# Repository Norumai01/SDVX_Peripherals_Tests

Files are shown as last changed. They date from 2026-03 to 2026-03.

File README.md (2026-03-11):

# controller_subtests

Breadboard prototyping tests for a custom Sound Voltex (SDVX) controller built on the Raspberry Pi Pico 2 H (RP2350).

Each subfolder is a self-contained test with its own `CMakeLists.txt` and `main.c`.

---

## Project Structure

```
controller_subtests/
├── CMakeLists.txt          ← top-level, registers all subtests
├── pico_sdk_import.cmake
├── serial_monitor.py       ← Python serial monitor for debugging
├── mx_switch_test/
│   ├── CMakeLists.txt
│   └── main.c              ← Cherry MX Brown button + onboard LED test
└── encoder_test/
    ├── CMakeLists.txt
    └── main.c              ← Bourns PEC11R rotary encoder test
```

---

## Hardware

| Component | Part |
|---|---|
| Microcontroller | Raspberry Pi Pico 2 H (RP2350, pre-soldered headers) |
| Buttons | Cherry MX Brown switches (jumper wires soldered directly to pins) |
| Encoders | Bourns PEC11R-xxxxK (no detents, with push switch) |

---

## Subtest: mx_switch_test

Tests a single Cherry MX Brown switch on GPIO 0. Jumper wires are soldered directly to the two switch pins. Toggles the onboard LED on press/release and prints state over USB serial.

**Wiring:**
```
Switch Pin 1  → GPIO 0  (pin 1)
Switch Pin 2  → GND
```

> **Note:** Uses the Pico's internal pull-up — no external resistor needed. Pin reads HIGH at rest and LOW when pressed.

---

## Subtest: encoder_test

Tests a Bourns PEC11R rotary encoder — quadrature rotation via interrupt and push switch via polling.

**Wiring:**
```
ENC A    → GPIO 10  (pin 14)
ENC C    → GND
ENC B    → GPIO 11  (pin 15)
SW pin 1 → GPIO 12  (pin 16)
SW pin 2 → GND
```

**How it works:**
- An interrupt fires on every rising/falling edge of channel A
- Inside the ISR, A and B are compared — if they differ, direction is CW (+1), if same, direction is CCW (-1)
- The push switch is polled in the main loop with debounce

---

## Building

Requires the [Raspberry Pi Pico SDK](https://github.com/raspberrypi/pico-sdk). Set `PICO_SDK_PATH` in your environment or let CLion handle it via the CMake Environment field.

```bash
mkdir cmake-build-debug && cd cmake-build-debug
cmake ..
make
```

Each subtest outputs its own `.uf2` into its own subfolder:
```
cmake-build-debug/
├── mx_switch_test/
│   └── mx_switch_test.uf2
└── encoder_test/
    └── encoder_test.uf2
```

**To flash:**
1. Hold BOOTSEL on the Pico while plugging in USB
2. It mounts as a drive called `RP2350`
3. Drag and drop the `.uf2` onto the `RP2350` drive

---

## Serial Monitor

Use the included `serial_monitor.py` to watch output over USB serial.

**Requirements:**
```bash
pip install pyserial
```

**Run:**
```bash
python serial_monitor.py
```

Defaults to `COM3` at `115200` baud. Edit `PORT` at the top of the script if your Pico is on a different port (check Device Manager → Ports (COM & LPT)).

## CLion Serial Monitor (alternative)

CLion has a built-in serial monitor under **Tools → Serial Monitor**.

Settings that must be enabled for it to work with the Pico:
- **Enable HW Flow Control** — on
- **Local Echo** — on
- **DTR** — enabled (this is what actually triggers the Pico to send output)

Without DTR enabled, the monitor connects but receives nothing.

---

## Notes

- Both encoder A and B pins use the Pico's internal pull-ups — no external resistors needed for basic testing
- For final PCB design, add a hardware filter (10KΩ + 0.01µF on each channel) per the PEC11R datasheet recommendation to reduce contact bounce at higher RPM
- The encoder's position counter is unbounded (`volatile int`) — for HID use, report the delta each frame rather than an absolute value

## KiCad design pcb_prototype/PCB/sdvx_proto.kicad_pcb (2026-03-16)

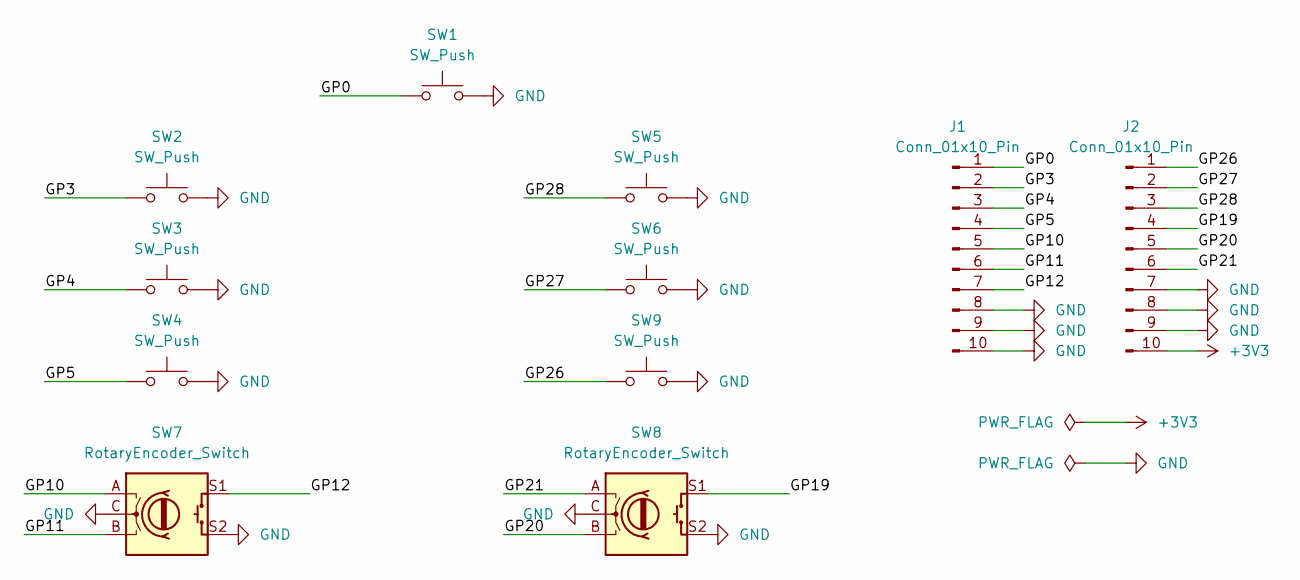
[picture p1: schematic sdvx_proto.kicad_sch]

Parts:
J1, J2: Conn_01x10_Pin; PinHeader_1x10_P2.54mm_Vertical
SW1, SW2, SW3, SW4, SW5, SW6, SW9: SW_Push; MX-Solderable-1U
SW7, SW8: RotaryEncoder_Switch; RotaryEncoder_Alps_EC11E-Switch_Vertical_H20mm

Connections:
+3V3: J2.10
/GP0: J1.1, SW1.1
/GP3: J1.2, SW2.1
/GP4: J1.3, SW3.1
/GP5: J1.4, SW4.1
/GP10: J1.5, SW7.A
/GP11: J1.6, SW7.B
/GP12: J1.7, SW7.S1
/GP19: J2.4, SW8.S1
/GP20: J2.5, SW8.B
/GP21: J2.6, SW8.A
/GP26: J2.1, SW9.1
/GP27: J2.2, SW6.1
/GP28: J2.3, SW5.1
GND: J1.8, J1.9, J1.10, J2.7, J2.8, J2.9, SW1.2, SW2.2, SW3.2, SW4.2, SW5.2, SW6.2, SW7.C, SW7.S2, SW8.C, SW8.S2, SW9.2

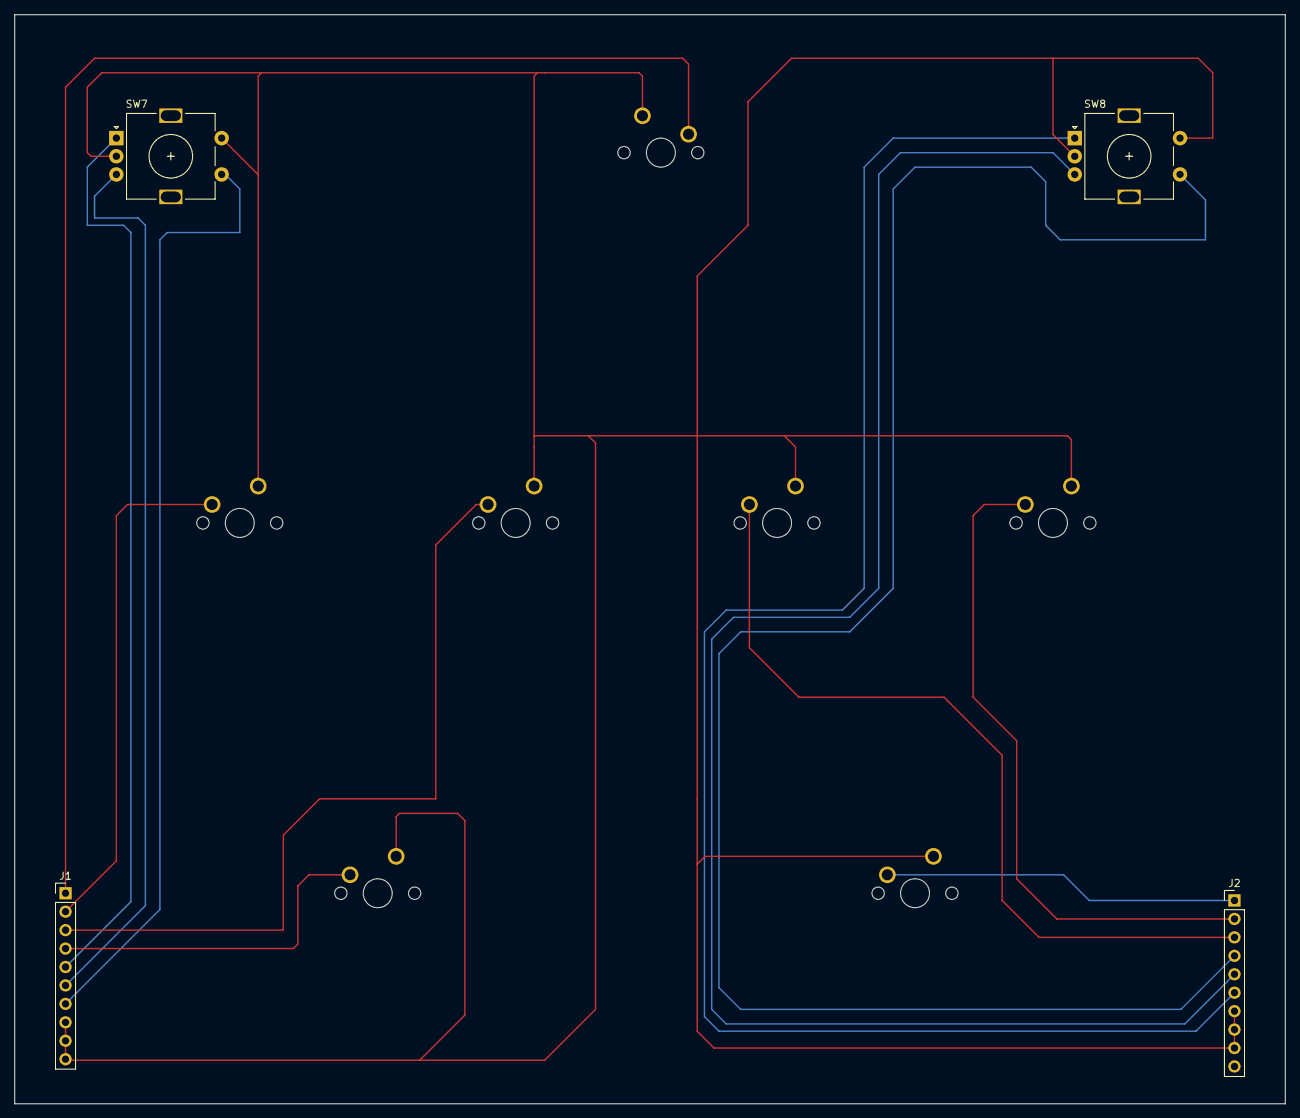
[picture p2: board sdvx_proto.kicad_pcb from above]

Board: 2 copper layers, 175.0 x 150.0 mm, 11 parts (1 on the bottom side), 14 nets.

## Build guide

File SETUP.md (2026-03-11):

# CLion + Pico 2 Setup Guide (Windows)

---

## First-Time Setup

Only needs to be done once per machine.

### 1. Install Python

Download and run the standalone installer from [python.org](https://python.org). During install, check **"Add Python to PATH"**.

Verify in a new PowerShell window:
```powershell
python --version
```

### 2. Install Git

Download from [git-scm.com](https://git-scm.com). Verify in a new PowerShell window:
```powershell
git --version
```

### 3. Clone the Pico SDK and Examples

Create a folder for your Pico work (example used here: `C:\pico`), then clone everything into it:
```powershell
cd C:\pico

git clone https://github.com/raspberrypi/pico-sdk.git --branch master
cd pico-sdk
git submodule update --init
cd ..

git clone https://github.com/raspberrypi/pico-examples.git --branch master
git clone https://github.com/raspberrypi/pico-extras.git
```

> You can use any folder you like. Just keep track of it — you'll need the path in later steps.

### 4. Install the ARM GNU Toolchain

Download the Windows toolchain from the [ARM Developer site](https://developer.arm.com/downloads/-/arm-gnu-toolchain-downloads). Extract it into your pico folder, e.g.:
```
C:\pico\arm_gnu_toolchain\
```

You should see folders called `bin`, `lib`, `arm-none-eabi`, etc. inside it.

### 5. Set Environment Variables

1. Press `Win` → search **"Environment Variables"** → click **"Edit the system environment variables"**
2. Click **Environment Variables...**
3. Under **User variables**, click **New** for each of the following:

| Variable Name | Value (adjust to your actual folder) |
|---|---|
| `PICO_SDK_PATH` | `C:\pico\pico-sdk` |
| `PICO_TOOLCHAIN_PATH` | `C:\pico\arm_gnu_toolchain` |
| `PICO_EXTRAS_PATH` | `C:\pico\pico-extras` |

4. Click OK on all dialogs, then **restart any open terminals or CLion** for changes to take effect.

### 6. Install CLion

Download and install CLion from [jetbrains.com/clion](https://www.jetbrains.com/clion/).

### 7. Configure the CLion Toolchain

Go to **File → Settings → Build, Execution, Deployment → Toolchains**

- Click **+** and select **MinGW**
- Set the C Compiler to your toolchain's gcc, e.g.:
  ```
  C:\pico\arm_gnu_toolchain\bin\arm-none-eabi-gcc.exe
  ```
- Set the C++ Compiler to:
  ```
  C:\pico\arm_gnu_toolchain\bin\arm-none-eabi-g++.exe
  ```

> **Why MinGW?** Picotool is a Windows binary that gets built during compilation using CLion's bundled MinGW GCC. Your actual Pico firmware uses the ARM compiler. Both are needed.

### 8. Install pyserial (for serial monitor)

```powershell
pip install pyserial
```

---

## Per-Project Setup

Do this every time you create a new project.

### 1. Create the Project Folder Structure

```
your_project/
├── CMakeLists.txt
├── pico_sdk_import.cmake    ← copy this from the SDK
└── src/
    └── main.c
```

Copy `pico_sdk_import.cmake` from your SDK folder:
```
<your PICO_SDK_PATH>\external\pico_sdk_import.cmake
```

### 2. CMakeLists.txt Template

Replace `YOUR_PROJECT_NAME` with your actual project name:

```cmake
cmake_minimum_required(VERSION 3.13)

include(pico_sdk_import.cmake)

project(YOUR_PROJECT_NAME C CXX ASM)
set(CMAKE_C_STANDARD 11)
set(CMAKE_CXX_STANDARD 17)

pico_sdk_init()

add_executable(YOUR_PROJECT_NAME
    src/main.c
)

target_link_libraries(YOUR_PROJECT_NAME
    pico_stdlib
    hardware_gpio
)

pico_enable_stdio_usb(YOUR_PROJECT_NAME 1)
pico_enable_stdio_uart(YOUR_PROJECT_NAME 0)

pico_add_extra_outputs(YOUR_PROJECT_NAME)
```

### 3. Open the Project in CLion

**File → Open** → select your project folder → OK

### 4. Configure CMake Settings

Go to **File → Settings → Build, Execution, Deployment → CMake**

**Toolchain:** MinGW

**CMake options** (replace `<TOOLCHAIN_PATH>` with your actual `PICO_TOOLCHAIN_PATH`):
```
-G Ninja -DPICO_BOARD=pico2 -DCMAKE_C_COMPILER="<TOOLCHAIN_PATH>\bin\arm-none-eabi-gcc.exe" -DCMAKE_CXX_COMPILER="<TOOLCHAIN_PATH>\bin\arm-none-eabi-g++.exe"
```

**Environment** (replace each `<...>` with your actual paths):
```
PICO_SDK_PATH=<your pico-sdk folder>;PICO_TOOLCHAIN_PATH=<your arm_gnu_toolchain folder>;PICO_EXTRAS_PATH=<your pico-extras folder>
```

Click **Apply → OK**.

### 5. Reset CMake and Build

**Tools → CMake → Reset Cache and Reload Project**

Then select your target from the dropdown at the top right and hit the **hammer icon** to build.

### 6. Flash to Pico

1. Hold **BOOTSEL** and plug in the Pico via USB
2. It mounts as a drive called `RP2350`
3. Find your `.uf2` in:
   ```
   your_project\cmake-build-debug-mingw\your_project.uf2
   ```
4. Drag and drop it onto the `RP2350` drive
5. The Pico reboots and runs your firmware

### 7. View Serial Output

Run in Python (with Pico already plugged in and running):

**Requirements:**
```bash
pip install pyserial
```

**Run:**
```bash
python serial_monitor.py
```

Defaults to `COM3` at `115200` baud. Edit `PORT` at the top of the script if your Pico is on a different port (check Device Manager → Ports (COM & LPT)).

> Check **Device Manager → Ports (COM & LPT)** if your Pico is not on COM3.

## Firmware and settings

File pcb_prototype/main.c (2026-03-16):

//
// main.c
// SDVX HID test — 1 button + 1 rotary encoder as a USB gamepad
//

#include <stdlib.h>
#include <stdio.h>
#include <string.h>

#include "bsp/board_api.h"
#include "tusb.h"
#include "usb_descriptors.h"
#include "hardware/gpio.h"

//--------------------------------------------------------------------+
// Pin Definitions
//--------------------------------------------------------------------+

#define BUTTON_START  0
#define BUTTON_BT_A   3
#define BUTTON_BT_B   4
#define BUTTON_BT_C   28
#define BUTTON_BT_D   27
#define BUTTON_FX_L   5
#define BUTTON_FX_R   26

#define ENC_L_A       10 // VOL-L button
#define ENC_L_B       11
#define ENC_L_SW      12  // encoder push button
#define ENC_R_A       21  // VOL-R button
#define ENC_R_B       20
#define ENC_R_SW      19  // encoder push button


//--------------------------------------------------------------------+
// Encoder State
//--------------------------------------------------------------------+

volatile int enc_l_position = 0;
volatile int enc_r_position = 0;

void encoder_isr(uint gpio, uint32_t events)
{
  switch (gpio) {
    case ENC_L_A: {
      bool a = gpio_get(ENC_L_A);
      bool b = gpio_get(ENC_L_B);
      enc_l_position += (a != b) ? 1 : -1;
      break;
    }
    case ENC_R_A: {
      bool a = gpio_get(ENC_R_A);
      bool b = gpio_get(ENC_R_B);
      enc_r_position += (a != b) ? 1 : -1;
      break;
    }
    default:
      return;
  }
}

//--------------------------------------------------------------------+
// GPIO Setup
//--------------------------------------------------------------------+

static void gpio_setup(void)
{
  // Buttons
  const uint button_pins[] = {
    BUTTON_START, BUTTON_BT_A, BUTTON_BT_B, BUTTON_BT_C,
    BUTTON_BT_D, BUTTON_FX_L, BUTTON_FX_R
  };

  for (int i = 0; i < 7; i++) {
    gpio_init(button_pins[i]);
    gpio_set_dir(button_pins[i], GPIO_IN);
    gpio_pull_up(button_pins[i]);
  }

  // Encoder L
  gpio_init(ENC_L_A);
  gpio_init(ENC_L_B);
  gpio_set_dir(ENC_L_A, GPIO_IN);
  gpio_set_dir(ENC_L_B, GPIO_IN);
  gpio_pull_up(ENC_L_A);
  gpio_pull_up(ENC_L_B);

  gpio_init(ENC_L_SW);
  gpio_set_dir(ENC_L_SW, GPIO_IN);
  gpio_pull_up(ENC_L_SW);

  // Encoder R
  gpio_init(ENC_R_A);
  gpio_init(ENC_R_B);
  gpio_set_dir(ENC_R_A, GPIO_IN);
  gpio_set_dir(ENC_R_B, GPIO_IN);
  gpio_pull_up(ENC_R_A);
  gpio_pull_up(ENC_R_B);

  gpio_init(ENC_R_SW);
  gpio_set_dir(ENC_R_SW, GPIO_IN);
  gpio_pull_up(ENC_R_SW);

  // Interrupts — register callback once, then enable second pin separately
  gpio_set_irq_enabled_with_callback(ENC_L_A,
    GPIO_IRQ_EDGE_RISE | GPIO_IRQ_EDGE_FALL, true, &encoder_isr);

  gpio_set_irq_enabled(ENC_R_A,
    GPIO_IRQ_EDGE_RISE | GPIO_IRQ_EDGE_FALL, true);
}

//--------------------------------------------------------------------+
// Blink
//--------------------------------------------------------------------+

/* Blink pattern
 * - 250 ms  : device not mounted
 * - 1000 ms : device mounted
 * - 2500 ms : device is suspended
 */
enum  {
  BLINK_NOT_MOUNTED = 250,
  BLINK_MOUNTED = 1000,
  BLINK_SUSPENDED = 2500,
};

static uint32_t blink_interval_ms = BLINK_NOT_MOUNTED;

void led_blinking_task(void)
{
  static uint32_t start_ms = 0;
  static bool led_state = false;

  // blink is disabled
  if (!blink_interval_ms) return;

  // Blink every interval ms
  if ( board_millis() - start_ms < blink_interval_ms) return; // not enough time
  start_ms += blink_interval_ms;

  board_led_write(led_state);
  led_state = !led_state; // toggle
}

//--------------------------------------------------------------------+
// Device callbacks
//--------------------------------------------------------------------+

// Invoked when device is mounted
void tud_mount_cb(void) { blink_interval_ms = BLINK_MOUNTED; }

// Invoked when device is unmounted
void tud_umount_cb(void) { blink_interval_ms = BLINK_NOT_MOUNTED; }

// Invoked when usb bus is suspended
void tud_suspend_cb(bool remote_wakeup_en)
{
  (void) remote_wakeup_en;
  blink_interval_ms = BLINK_SUSPENDED;
}

// Invoked when usb bus is resumed
void tud_resume_cb(void)
{
  blink_interval_ms = tud_mounted() ? BLINK_MOUNTED : BLINK_NOT_MOUNTED;
}

//--------------------------------------------------------------------+
// HID Task — runs every 10ms
//--------------------------------------------------------------------+

void hid_task(void)
{
  // Poll every 10ms
  const uint32_t interval_ms = 10;
  static uint32_t start_ms = 0;

  if ( board_millis() - start_ms < interval_ms) return; // not enough time
  start_ms += interval_ms;

  if (!tud_hid_ready()) return;

  // --- Read encoder delta since last report ---
  static int last_l_pos = 0, last_r_pos = 0;
  int delta_l = enc_l_position - last_l_pos;
  int delta_r = enc_r_position - last_r_pos;
  last_l_pos = enc_l_position;
  last_r_pos = enc_r_position;

  // Clamp delta to int8_t range (-127 to 127) just in case of fast spinning
  if (delta_l >  127) delta_l =  127;
  if (delta_l < -127) delta_l = -127;
  if (delta_r >  127) delta_r =  127;
  if (delta_r < -127) delta_r = -127;

  // --- Build gamepad report ---
  hid_gamepad_report_t report = { 0 };

  // Button 0 = your MX switch
  report.buttons =
  (!gpio_get(BUTTON_BT_A)  ? (1 << 0) : 0) |
  (!gpio_get(BUTTON_BT_B)  ? (1 << 1) : 0) |
  (!gpio_get(BUTTON_BT_C)  ? (1 << 2) : 0) |
  (!gpio_get(BUTTON_BT_D)  ? (1 << 3) : 0) |
  (!gpio_get(BUTTON_FX_L)  ? (1 << 4) : 0) |
  (!gpio_get(BUTTON_FX_R)  ? (1 << 5) : 0) |
  (!gpio_get(BUTTON_START) ? (1 << 6) : 0);

  // encoder delta (-127 to 127)
  report.x = (int8_t) delta_l;  // VOL-L
  report.rx = (int8_t) delta_r; // VOL-R

  tud_hid_report(REPORT_ID_GAMEPAD, &report, sizeof(report));
}

//--------------------------------------------------------------------+
// HID Callbacks (required by TinyUSB)
//--------------------------------------------------------------------+

uint16_t tud_hid_get_report_cb(uint8_t instance, uint8_t report_id,
                                hid_report_type_t report_type,
                                uint8_t *buffer, uint16_t reqlen)
{
  (void) instance; (void) report_id; (void) report_type;
  (void) buffer;   (void) reqlen;
  return 0;
}

// Empty because PC doesn't need to send anything back. Just recieve inputs from controller.
void tud_hid_set_report_cb(uint8_t instance, uint8_t report_id,
                            hid_report_type_t report_type,
                            uint8_t const *buffer, uint16_t bufsize)
{
  (void) instance; (void) report_id; (void) report_type;
  (void) buffer;   (void) bufsize;
}

//--------------------------------------------------------------------+
// Main
//--------------------------------------------------------------------+

int main(void)
{
  board_init();
  gpio_setup();

  // TinyUSB init
  tud_init(BOARD_TUD_RHPORT);

  if (board_init_after_tusb) {
    board_init_after_tusb();
  }

  while (1)
  {
    tud_task();
    led_blinking_task();
    hid_task();
  }
}

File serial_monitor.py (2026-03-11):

import serial
import sys
from datetime import datetime

PORT = "COM3"
BAUD = 115200

def main():
    print(f"Connecting to {PORT} at {BAUD} baud...")
    print("Press Ctrl+C to exit\n")

    try:
        with serial.Serial(PORT, BAUD, timeout=1) as ser:
            print(f"Connected! Waiting for data...\n{'-' * 40}")
            while True:
                line = ser.readline()
                if line:
                    text = line.decode("utf-8", errors="replace").strip()
                    timestamp = datetime.now().strftime("%H:%M:%S.%f")[:-3]
                    print(f"[{timestamp}] {text}")

    except serial.SerialException as e:
        print(f"\nError: {e}")
        print("Make sure your Pico is plugged in and COM3 is correct.")
        print("Check Device Manager if unsure which COM port to use.")
        sys.exit(1)

    except KeyboardInterrupt:
        print("\n\nDisconnected.")

if __name__ == "__main__":
    main()

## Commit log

2026-03-11 I'm batman. Added peripheal tests for mx keyboard button and rotary encoders.
2026-03-12 Tested with both button and encoder and implement connection with usb to PC.
2026-03-16 Added PCB prototype and code for testing it.
    [sdvx_proto-B_Cu.gbr, sdvx_proto-B_Mask.gbr, sdvx_proto-B_Silkscreen.gbr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]
